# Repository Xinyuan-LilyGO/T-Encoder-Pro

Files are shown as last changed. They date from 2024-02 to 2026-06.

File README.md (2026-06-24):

<!--
 * @Description: None
 * @Author: LILYGO_L
 * @Date: 2023-09-11 16:13:14
 * @LastEditTime: 2026-06-24 11:30:23
 * @License: GPL 3.0
-->
<h1 align = "center">T-Encoder-Pro</h1>

<p align="center" width="100%">
    
</p>

<p> 
  <a href="https://www.arduino.cc/"> Arduino_badge</a>
</p> 

## **English | [中文](./README_CN.md)**

## Version iteration:
| Version | Update date |
| :---: | :---: |
| T-Encoder-Pro_V1.0 | 2024-02-02 |

## PurchaseLink
| Product | SOC |  FLASH  |  PSRAM | Link |
| :---: | :---: |:---: | :---: | :---: |
| T-Encoder-Pro_V1.0 | ESP32S3R8 | 16M |8M (Octal SPI)| [LILYGO Mall](https://www.lilygo.cc/products/t-encoder-plus) <br /> [Banggood Mall](https://m.banggood.in/LILYGO-T-Encoder-Pro-ESP32-S3-Rotary-Encoder-CHSC5816-ESP32-S3FN4R2-Circuit-Board-1_2-inch-AMOLED-Touch-Display-Wireless-Module-p-2018774.html) |

## Directory
- [Describe](#describe)
- [Preview](#preview)
- [Module](#module)
- [QuickStart](#quickstart)
- [PinOverview](#pinoverview)
- [FAQ](#faq)
- [Project](#project)
- [Information](#information)
- [DependentLibraries](#dependentlibraries)

## Describe

 T-Encoder-Pro is a smart control knob equipped with a AMOLED touch screen, based on the ESP32S3R8 chip. The knob rotates, clicks (pushes in), and contains a beeper and vibration motor.

## Preview

### Actual Product Image

<p align="center" width="100%">
    
</p>

---

<p align="center" width="100%">
    
</p>

---

<p align="center" width="100%">
    
</p>

## Module

### 1. MCU

* Chip: ESP32-S3-R8
* PSRAM: 8M (Octal SPI) 
* FLASH: 16M
* For more details, please visit [Espressif ESP32-S3 Datashee](https://www.espressif.com.cn/sites/default/files/documentation/esp32-s3_datasheet_en.pdf)

### 2. Screen and Touch

> **Model: DXQ120MYB2416A**
> * Size: 2.04-inch round screen
> * Screen type: AMOLED
> * Display driver IC: SH8601
> * Touch driver IC: CHSC5816
> * Dependency library: Arduino_GFX
> * Bus communication protocols: QSPI, I2C

> **Model: TFD12MASBCTB4_V0_07**
> * Screen type: AMOLED
> * Display driver IC: CO5300
> * Touch driver IC: CST816
> * Dependency library: Arduino_GFX
> * Bus communication protocols: QSPI, I2C

> [!NOTE]
> TFD12MASBCTB4_V0_07 is the latest version of the screen.

### 3. Rotary Encoder

* Characteristic: Supports left and right rotation

### 4. Buzzer

## QuickStart

### Examples Support

| Example | Support IDE And Version| Description | Picture |
| ---  | ---  | --- | --- |
| [GFX](./examples/GFX) | `[Arduino IDE][esp32_v3.0.7]` |  |  |
| [Lvgl_CIT](./examples/Lvgl_CIT) |`[Arduino IDE][esp32_v3.0.7]` | Product factory original testing |  |
| [CHSC5816](./examples/CHSC5816) | `[Arduino IDE][esp32_v3.0.7]` |  |  |
| [Rotary_Encoder](./examples/Rotary_Encoder) | `[Arduino IDE][esp32_v3.0.7]` |  |  |

| Firmware | Description | Picture |
| ---  | ---  | --- |
| [Lvgl_CIT](./firmware/[T-Encoder-Pro_V1.0][Lvgl_CIT]_firmware_V1.0.0.bin) | factory original testing screenDXQ120MYB2416A |  |
| [Lvgl_CIT](./firmware/(添加开机蜂鸣器)[T-Encoder-Pro_V1.0][Lvgl_CIT][Screen_TFD12MASBCTB4_V0_07]_firmware_202512061209.bin) | factory original testing screen TFD12MASBCTB4_V0_07  |  |

### PlatformIO
1. Install [VisualStudioCode](https://code.visualstudio.com/Download),choose installation based on your system type.

2. Open the "Extension" section of the Visual Studio Code software sidebar (Alternatively, use "<kbd>Ctrl</kbd>+<kbd>Shift</kbd>+<kbd>X</kbd>" to open the extension). Search for the "PlatformIO IDE" extension and download it.

3. During the installation of the extension, you can go to GitHub to download the program. You can download the main branch by clicking on the "<> Code" with green text, or you can download the program versions from the "Releases" section in the sidebar.

4. After the installation of the extension is completed, open the Explorer in the sidebar (Alternatively, use "<kbd>Ctrl</kbd>+<kbd>Shift</kbd>+<kbd>E</kbd>" go open it). Click on "Open Folder", locate the project code you just downloaded (the entire folder), and click "Add." At this point, the project files will be added to your workspace.

5. Open the "platformio.ini" file in the project folder (PlatformIO will automatically open the "platformio.ini" file corresponding to the added folder). Under the "[platformio]" section, uncomment and select the example program you want to burn (it should start with "default_envs = xxx") Then click "<kbd>[√](image/4.png)</kbd>" in the bottom left corner to compile. If the compilation is correct, connect the microcontroller to the computer and click "<kbd>[→](image/5.png)</kbd>" in the bottom left corner to download the program.

### Arduino
1. Install [Arduino](https://www.arduino.cc/en/software), choose installation based on your system type.

2. Open the "example" directory within the project folder, select the example project folder, and open the file ending with ".ino" to open the Arduino IDE project workspace.

3. Open the "Tools" menu at the top right -> Select "Board" -> "Board Manager." Find or search for "esp32" and download the board files from the author named "Espressif Systems." Then, go back to the "Board" menu and select the development board type under "ESP32 Arduino." The selected development board type should match the one specified in the "platformio.ini" file under the [env] section with the header "board = xxx." If there is no corresponding development board, you may need to manually add the development board from the "board" directory within your project folder.

4. Open menu bar "[File](image/6.png)" -> "[Preferences](image/6.png)", find "[Sketchbook location](image/7.png)" here, copy and paste all library files and folders from the "libraries" folder in the project directory into the "libraries" folder in this directory.

5. Select the correct settings in the Tools menu, as shown in the table below.

| Setting | Value |
| :---: | :---: |
| Board | ESP32S3 Dev Module|
| Upload Speed | 921600 |
| USB Mode | Hardware CDC and JTAG |
| USB CDC On Boot | Enabled |
| USB Firmware MSC On Boot | Disabled |
| USB DFU On Boot | Disabled |
| CPU Frequency | 240MHz (WiFi) |
| Flash Mode | QIO 80MHz |
| Flash Size | 16MB (128Mb) |
| Core Debug Level | None |
| Partition Scheme | 16M Flash (3MB APP/9.9MB FATFS) |
| PSRAM | OPI PSRAM |
| Arduino Runs On | Core 1 |
| Events Run On | Core 1 |

6. Select the correct port.

7. Click "<kbd>[√](image/8.png)</kbd>" in the upper right corner to compile. If the compilation is correct, connect the microcontroller to the computer, click "<kbd>[→](image/9.png)</kbd>" in the upper right corner to download.

### Firmware download
1. Open the project file "tools" and locate the ESP32 burning tool. Open it.

2. Select the correct burning chip and burning method, then click "OK." As shown in the picture, follow steps 1->2->3->4->5 to burn the program. If the burning is not successful, press and hold the "BOOT-0" button and then download and burn again.

3. Burn the file in the root directory of the project file "[firmware](./firmware/)" file, there is a description of the firmware file version inside, just choose the appropriate version to download.

<p align="center" width="100%">
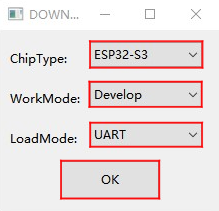
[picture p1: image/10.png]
    
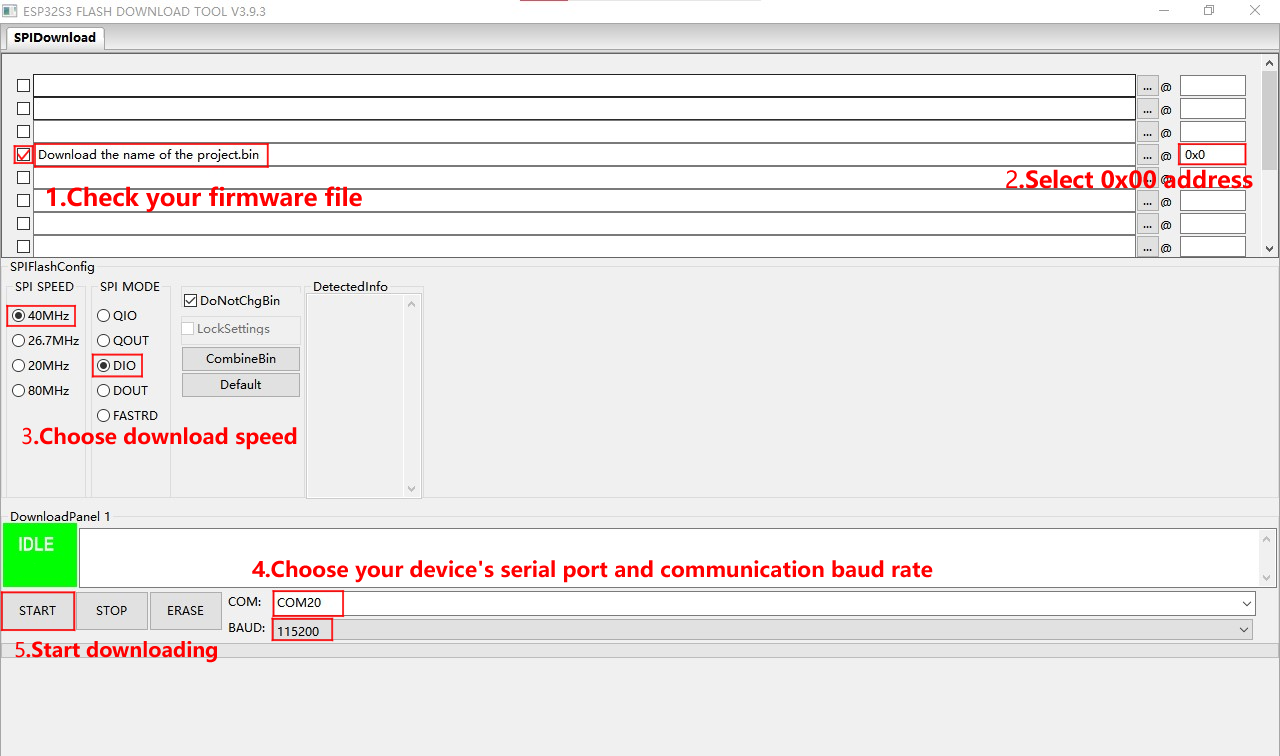
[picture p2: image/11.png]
    
</p>

## PinOverview

| Screen PIN | ESP32S3 PIN |
| :---: | :---:|
| SDIO0 | IO11 |
| SDIO1 | IO13 |
| SDIO2 | IO7 |
| SDIO3 | IO14 |
| SCLK | IO12 |
| RST | IO4 |
| VCI EN |  IO3 |
| CS | IO10 |

| Touch PIN | ESP32S3 PIN |
| :---: | :---:|
| RST | IO8 |
| INT | IO9 |
| SDA | IO5 |
| SCL | IO6 |

| Rotary Encoder PIN | ESP32S3 PIN |
| :---: | :---:|
| KNOB DATA A | IO1 |
| KNOB DATA B | IO2 |
| KNOB KEY | IO0 |

| Buzzer PIN | ESP32S3 PIN |
| :---: | :---:|
| BUZZER DATA | IO17 |

## FAQ

* Q. After reading the above tutorials, I still don't know how to build a programming environment. What should I do?
* A. If you still don't understand how to build an environment after reading the above tutorials, you can refer to the [LilyGo-Document](https://github.com/Xinyuan-LilyGO/LilyGo-Document) document instructions to build it.

<br />

* Q. Why does Arduino IDE prompt me to update library files when I open it? Should I update them or not?
* A. Choose not to update library files. Different versions of library files may not be mutually compatible, so it is not recommended to update library files.

<br />

* Q. Why is there no serial data output on the "Uart" interface on my board? Is it defective and unusable?
* A. The default project configuration uses the USB interface as Uart0 serial output for debugging purposes. The "Uart" interface is connected to Uart0, so it won't output any data without configuration.<br />For PlatformIO users, please open the project file "platformio.ini" and modify the option under "build_flags = xxx" from "-D ARDUINO_USB_CDC_ON_BOOT=true" to "-D ARDUINO_USB_CDC_ON_BOOT=false" to enable external "Uart" interface.<br />For Arduino users, open the "Tools" menu and select "USB CDC On Boot: Disabled" to enable the external "Uart" interface.

<br />

* Q. Why is my board continuously failing to download the program?
* A. Please hold down the "BOOT" button and try downloading the program again.The following is the illustration of the BOOT button.

<p align="center" width="100%">
    BOOT
</p>

<br />

## Project
* [SCH_T-Encoder-Pro_V1.0](project/[SCH][T-Encoder-Pro_V1.0].pdf)
* [SCH_T-Encoder-Pro_V1.0_TFT_FPC](project/[SCH][T-Encoder-Pro_V1.0][TFT_FPC].pdf)

## Information
* [Espressif](https://www.espressif.com/en/support/documents/technical-documents)
* [DXQ120MYB2416A](information/DXQ120MYB2416A.pdf)
* [DS_CHSC5816_V1.1.5](information/DS_CHSC5816_V1.1.5.pdf)
* [CHSC5816-ApplicationDoc_US_V04](information/CHSC5816-ApplicationDoc_US_V04.pdf)

## DependentLibraries
* [Arduino_GFX-1.5.0](https://github.com/moononournation/Arduino_GFX)
* [lvgl-8.3.5](https://github.com/lvgl/lvgl)
* [SensorLib-0.1.4](https://github.com/lewisxhe/SensorsLib)

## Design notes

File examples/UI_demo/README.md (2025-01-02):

This routine runs only in the `PlatformIO` environment

Compilation errors may occur in `Arduino` environments

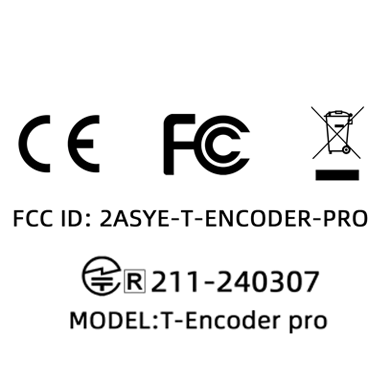
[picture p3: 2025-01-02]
examples/UI_demo/assets/img/electronic_tag.png

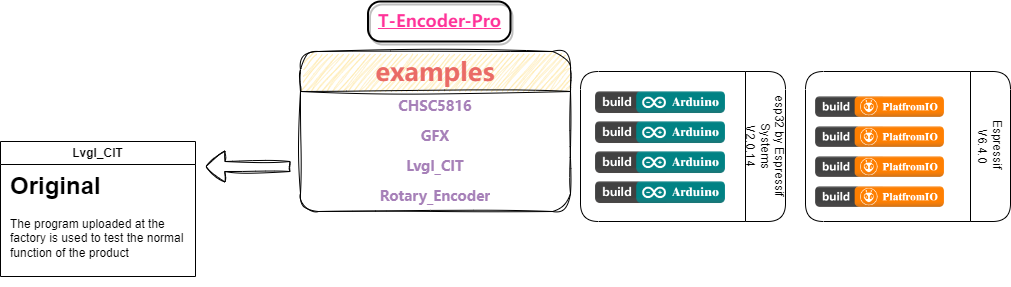
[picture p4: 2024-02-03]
image/T-Encoder-Pro_Example_Support.png

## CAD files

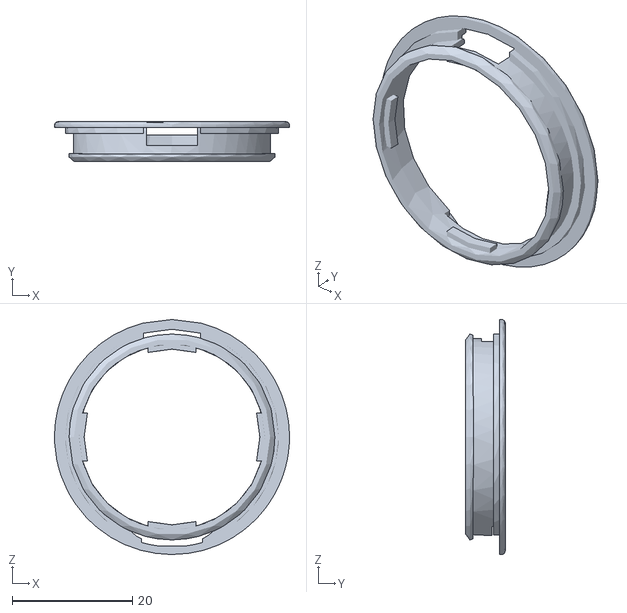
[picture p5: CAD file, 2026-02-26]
structure/H670-STL/0-00_26_4_23_7_30.stl
39.0 x 6.60 x 39.0

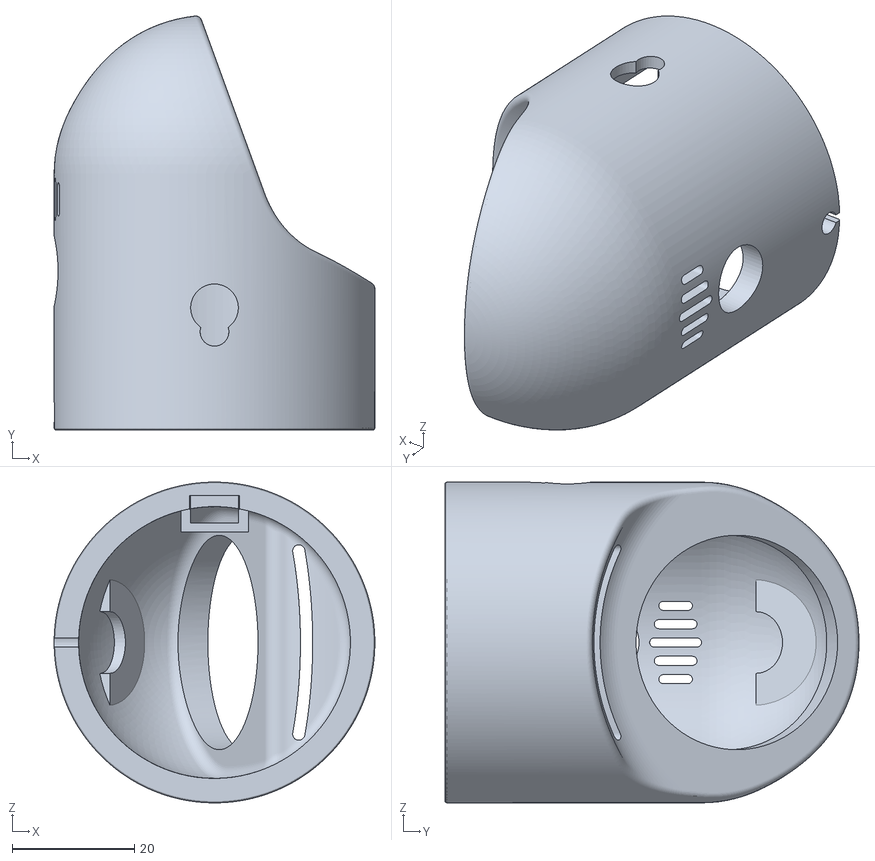
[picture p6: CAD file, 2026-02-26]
structure/zhijia.stl
52.5 x 67.8 x 52.5

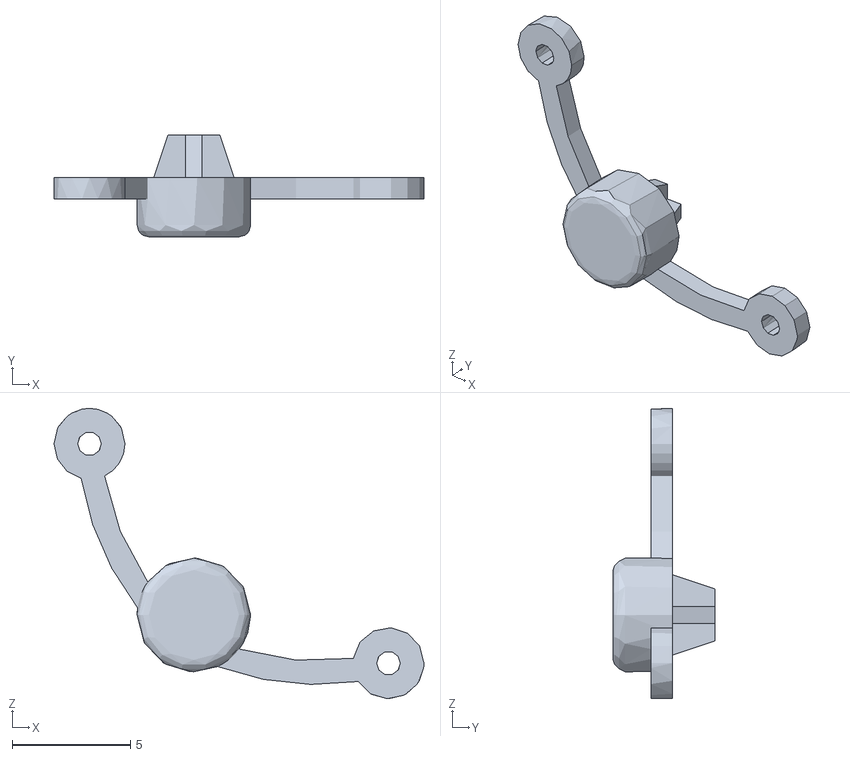
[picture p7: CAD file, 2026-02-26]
structure/H670-STL/0-00_15.stl
15.6 x 4.30 x 12.3

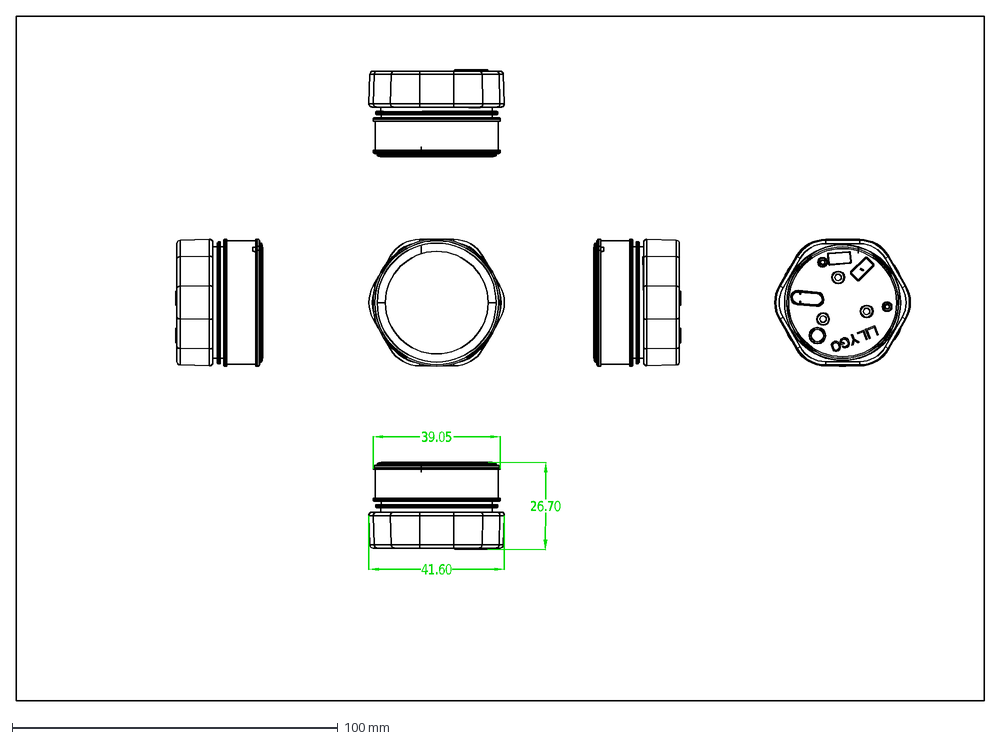
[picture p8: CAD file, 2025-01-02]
structure/Shell.dxf
26.70
41.60
39.05

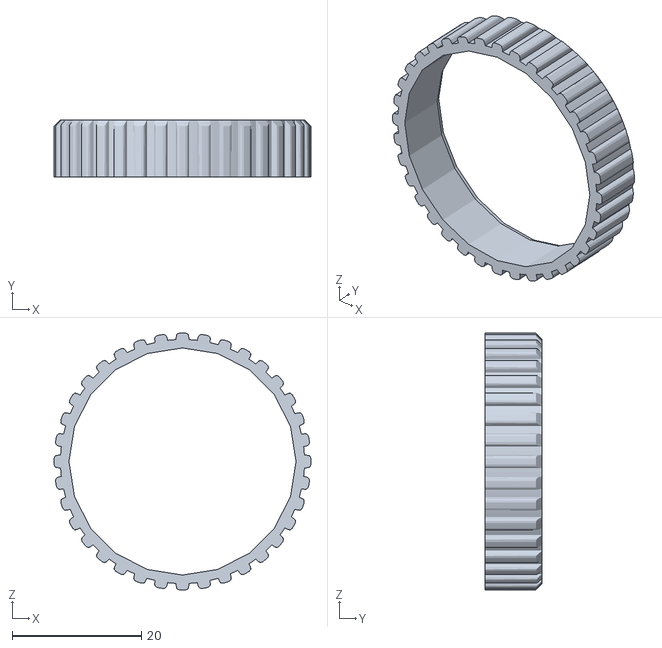
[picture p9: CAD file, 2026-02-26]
structure/H670-STL/0-00_10_5_12.stl
39.8 x 8.90 x 39.8

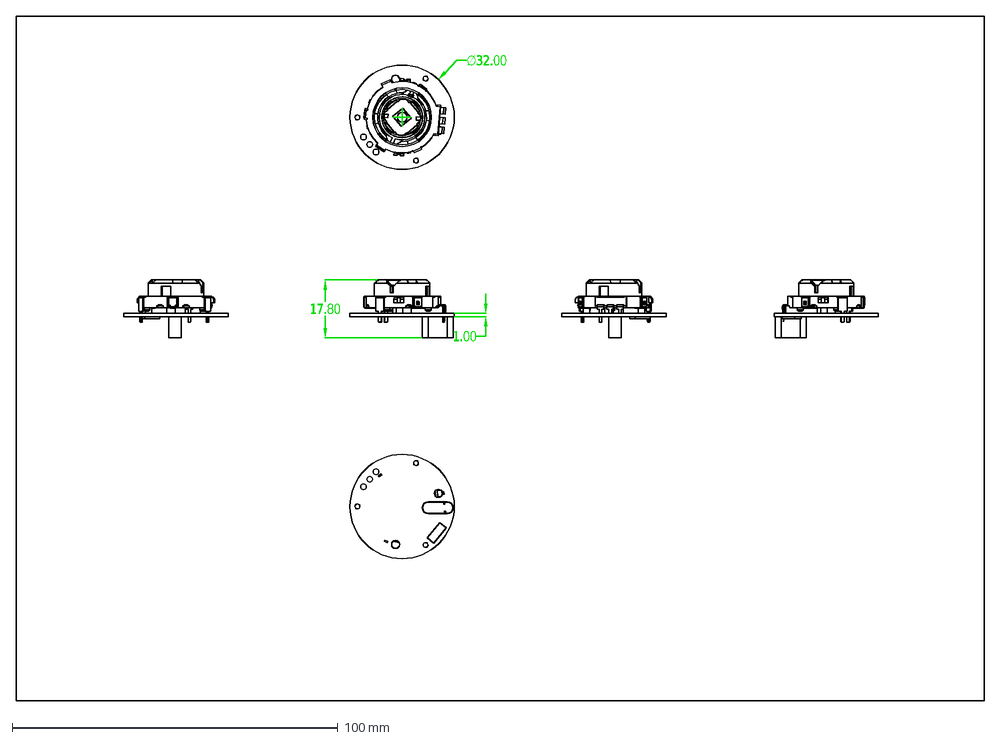
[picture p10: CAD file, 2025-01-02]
structure/PCB.dxf
∅32.00
17.80
1.00

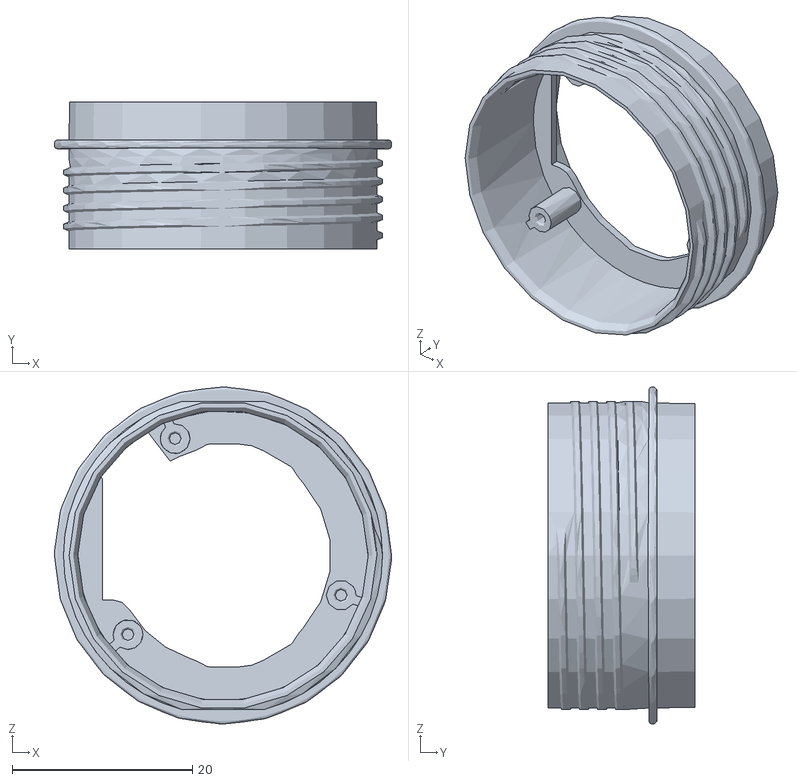
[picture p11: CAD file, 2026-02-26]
structure/H670-STL/0-00_22_30_1.stl
37.4 x 16.3 x 37.4

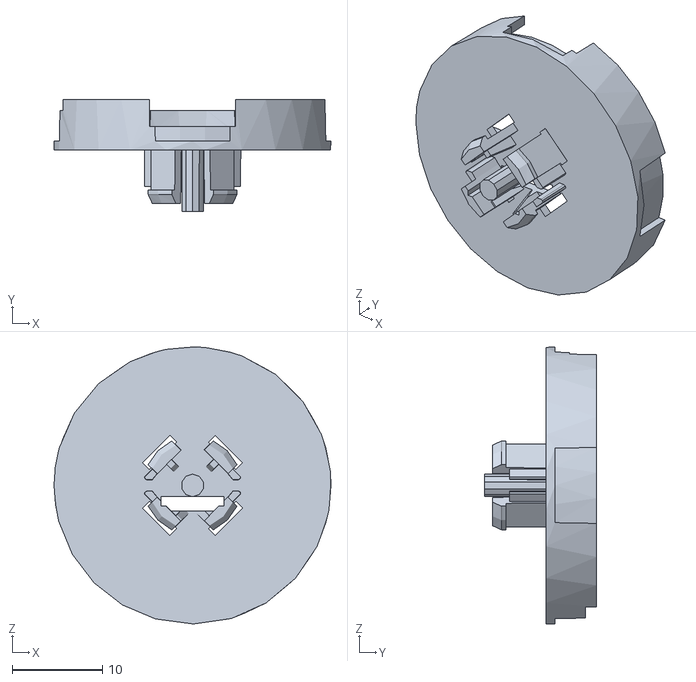
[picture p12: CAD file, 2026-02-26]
structure/H670-STL/0-00_27_3_20_15_33.stl
30.6 x 12.4 x 30.6

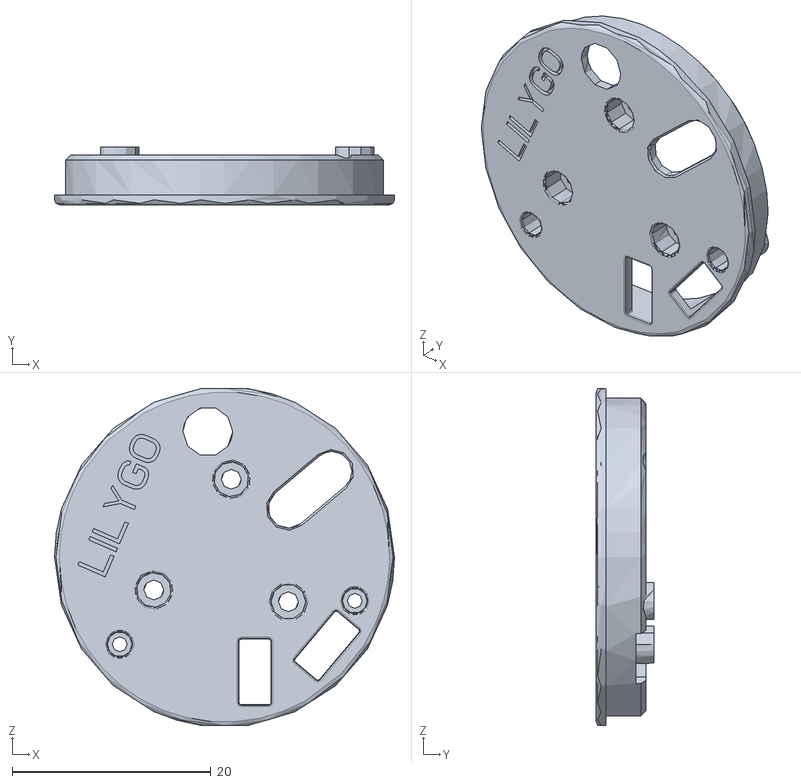
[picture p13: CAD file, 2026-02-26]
structure/H670-STL/0-001_10.stl
34.2 x 5.80 x 33.9

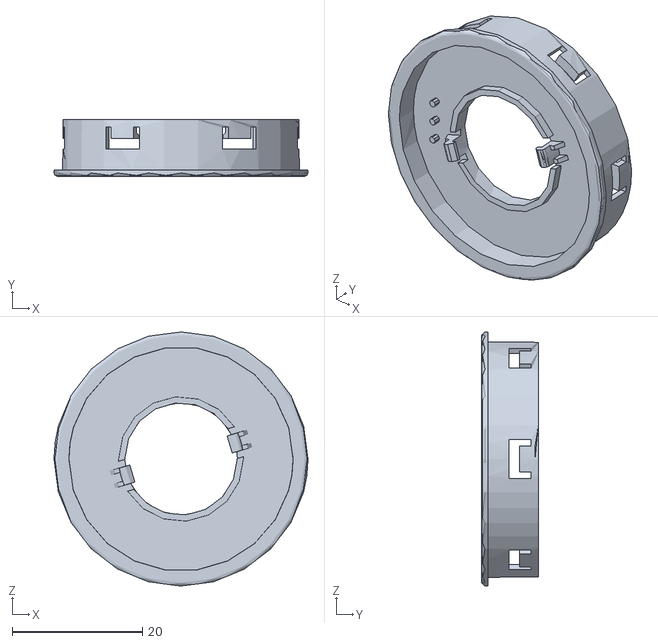
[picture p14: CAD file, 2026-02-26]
structure/H670-STL/0-00_44_4_15_33_10.stl
39.0 x 8.70 x 39.0

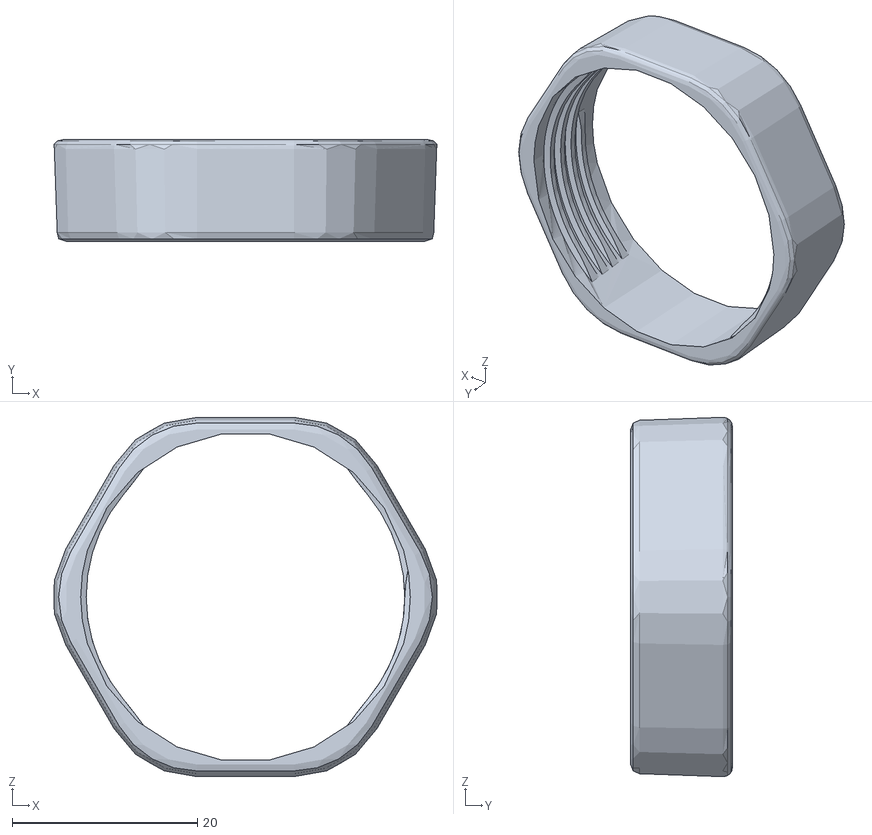
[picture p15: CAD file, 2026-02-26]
structure/H670-STL/0-00_38_1.stl
41.4 x 11.0 x 38.8

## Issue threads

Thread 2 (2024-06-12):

Display physical stability

nikthefix, 2024-06-12:
Received this unit today.
Display looks fantastic!
Love the form factor.
Love the packaging.

On my unit the display glass is able to rotate +/- a degree or so with respect to the main board housing when turning the encoder.
I'm concerned that this can't be good for the FFC connection to the main board.
I imagine it's just tolerances in the sub-assemblies.

Could you upload a step model of the internals?

May I also suggest for future iterations that the encoder silicone ring be increased in diameter to avoid interference with the display glass bezel when operating. 2mm diameter increase would be nice and still look cool and compact.

Many thanks for another terrific product.
Really looking forward to the T-Circle-S3-AMOLED-1.43 and T-Display-AMOLED-1.64

nik

awilley, 2024-07-04:
I agree about the encoder ring. Really needs to be larger. Will still look great.

nikthefix, 2024-07-04:
@awilley
I'm temporarily using the foam insert ring which came in the packaging. It's about the right size for me.
I'm gonna try to construct a contoured brushed aluminium ring - like a mini Nest thermostat.
I think that for this sort of product, an absolute magnetic encoder with no detents would be better. The 'detents' could then be haptics from the mini speaker - nicer for a dial with an undefined application. If the encoder was inductive then the ring hardware could be fabricated from traces on pcb material - no magnets or hall sensors, just a small cheap inductive positional sensor (LX3302A).

awilley, 2024-07-04:
@nikthefix lol, I also kept the foam ring on mine. Shoot me a picture of the ring when you get it built.
I agree about the detents. I was thinking of using a compact haptic motor like 1597-1244-ND (part id) on digikey or similar. Didn't think of just using the speaker, but that's clever and might work well enough depending on the speaker.
That inductive sensor looks really interesting for this.
I think this has to be tried.
Are you planning on putting something together?
I was at one point planning to build a more compact (in height) version of this for some of my small project applications I have.

nikthefix, 2024-07-06:
@awilley Yes I'm preparing an inductive ring design for the 1.43" amoled when it is launched. I only have lilgo drawings at this point but it will be the perfect test bed and saves me having to make a custom board. I already experimented with a linear scale inductive encoder using the Microchip ic. It's a fantastic solution which really works and can be made cheaply to just about any 2D form factor. The esp has to decode the relationship between 2 continuous sinewaves - which it can do with no sweat!

Llgok, 2025-01-02:
Closed due to prolonged inactivity.

Closed 2025-01-02.

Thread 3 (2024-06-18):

Square Line Studio Smart Watch Demo

nikthefix, 2024-06-18:
Here's a demo for the T-Encoder-Pro based on the Square Line Studio Smart Watch Project.
It's refactored for ESP32_Arduino 3.0.1 and requires LVGL 8.3.11 but does not require Arduino_GFX.

Please read the notes at the top of the .ino

[Lilygo_T_Encoder_pro_smart_watch.zip](https://github.com/user-attachments/files/15891249/Lilygo_T_Encoder_pro_smart_watch.zip)

https://github.com/nikthefix/Lilygo_support_T_Encoder_Pro

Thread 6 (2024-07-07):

Errors when compiling examples/GFX/GFX.ino In IDE 2.32

markeby, 2024-07-07:
In file included from c:\Users\markeby\Documents\Arduino\libraries\Arduino_GFX-1.3.7\src/Arduino_GFX_Library.h:4,
from B:\tmp\Encoder\examples\GFX\GFX.ino:16:...\Arduino\libraries\Arduino_GFX-1.3.7\src/Arduino_DataBus.h:167:13: error: 'i80_device_list' has not been declared
167 | LIST_HEAD(i80_device_list, lcd_panel_io_i80_t)

...\Arduino\libraries\Arduino_GFX-1.3.7\src/Arduino_DataBus.h:168:3: error: 'device_list' does not name a type
168 | device_list; // Head of i80 device list

...\Arduino\libraries\Arduino_GFX-1.3.7\src/Arduino_DataBus.h:202:3: error: ISO C++ forbids declaration of 'LIST_ENTRY' with no type [-fpermissive]
202 | LIST_ENTRY(lcd_panel_io_i80_t)

In file included from c:\Users\markeby\Documents\Arduino\libraries\Arduino_GFX-1.3.7\src/Arduino_GFX_Library.h:17:
c:\Users\markeby\Documents\Arduino\libraries\Arduino_GFX-1.3.7\src/databus/Arduino_ESP32RGBPanel.h:43:3: error: 'esp_lcd_rgb_panel_frame_trans_done_cb_t' does not name a type; did you mean 'esp_lcd_panel_io_color_trans_done_cb_t'?
43 | esp_lcd_rgb_panel_frame_trans_done_cb_t on_frame_trans_done; // Callback, invoked after frame trans done

Llgok, 2024-07-10:
@markeby
Currently, the T-Encoder-Pro example code only supports the arduino-esp32-libs_V2.0.14 version. Compiling with the arduino-esp32-libs_V2.0.14 version will not result in any errors.

Closed 2024-07-19.

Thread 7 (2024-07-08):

Issue with compiling T-Encoder Pro Example Sketches

arnie2321, 2024-07-08:
I'm getting lots of errors when compiling the Lvgl_CIT sketch that I pulled from the GitHub examples folder for the T-Encoder Pro.  Mainly seems like issues with library dependencies.   A couple of the other example sketches, Rotary_Encoder and CHSC5816 do compile and run on the T-Encoder.  The GFX example won't compile either.   I'm working in Arduino IDE 2.3.1.  Help from the community or developer would be welcomed.

Lvgl_CIT Compile Errors:

In file included from c:\Users\MyPC\Documents\Arduino\libraries\Arduino_GFX-1.3.7\src/Arduino_GFX_Library.h:4,
                 from C:\Users\MyPC\Documents\Arduino\T-Encoder-Pro-main\examples\Lvgl_CIT\custom.h:13,
                 from C:\Users\MyPC\Documents\Arduino\T-Encoder-Pro-main\examples\Lvgl_CIT\Lvgl_CIT.ino:15:
c:\Users\MyPC\Documents\Arduino\libraries\Arduino_GFX-1.3.7\src/Arduino_DataBus.h:167:13: error: 'i80_device_list' has not been declared
  167 |   LIST_HEAD(i80_device_list, lcd_panel_io_i80_t)
      |             ^~~~~~~~~~~~~~~
c:\Users\MyPC\Documents\Arduino\libraries\Arduino_GFX-1.3.7\src/Arduino_DataBus.h:167:3: error: ISO C++ forbids declaration of 'LIST_HEAD' with no type [-fpermissive]
  167 |   LIST_HEAD(i80_device_list, lcd_panel_io_i80_t)
      |   ^~~~~~~~~
c:\Users\MyPC\Documents\Arduino\libraries\Arduino_GFX-1.3.7\src/Arduino_DataBus.h:167:48: error: expected ';' at end of member declaration
  167 |   LIST_HEAD(i80_device_list, lcd_panel_io_i80_t)
      |                                                ^
      |                                                 ;
c:\Users\MyPC\Documents\Arduino\libraries\Arduino_GFX-1.3.7\src/Arduino_DataBus.h:168:3: error: 'device_list' does not name a type
  168 |   device_list; // Head of i80 device list
      |   ^~~~~~~~~~~
c:\Users\MyPC\Documents\Arduino\libraries\Arduino_GFX-1.3.7\src/Arduino_DataBus.h:202:3: error: ISO C++ forbids declaration of 'LIST_ENTRY' with no type [-fpermissive]
  202 |   LIST_ENTRY(lcd_panel_io_i80_t)
      |   ^~~~~~~~~~
c:\Users\MyPC\Documents\Arduino\libraries\Arduino_GFX-1.3.7\src/Arduino_DataBus.h:202:32: error: expected ';' at end of member declaration
  202 |   LIST_ENTRY(lcd_panel_io_i80_t)
      |                                ^
      |                                 ;
c:\Users\MyPC\Documents\Arduino\libraries\Arduino_GFX-1.3.7\src/Arduino_DataBus.h:203:3: error: 'device_list_entry' does not name a type
  203 |   device_list_entry; // Entry of i80 device list
      |   ^~~~~~~~~~~~~~~~~
In file included from c:\Users\MyPC\Documents\Arduino\libraries\Arduino_GFX-1.3.7\src/Arduino_GFX_Library.h:17:
c:\Users\MyPC\Documents\Arduino\libraries\Arduino_GFX-1.3.7\src/databus/Arduino_ESP32RGBPanel.h:43:3: error: 'esp_lcd_rgb_panel_frame_trans_done_cb_t' does not name a type; did you mean 'esp_lcd_panel_io_color_trans_done_cb_t'?
   43 |   esp_lcd_rgb_panel_frame_trans_done_cb_t on_frame_trans_done; // Callback, invoked after frame trans done
      |   ^~~~~~~~~~~~~~~~~~~~~~~~~~~~~~~~~~~~~~~
      |   esp_lcd_panel_io_color_trans_done_cb_t
C:\Users\MyPC\Documents\Arduino\T-Encoder-Pro-main\examples\Lvgl_CIT\Lvgl_CIT.ino: In function 'void setup()':
C:\Users\MyPC\Documents\Arduino\T-Encoder-Pro-main\examples\Lvgl_CIT\Lvgl_CIT.ino:142:5: error: 'ledcAttachPin' was not declared in this scope; did you mean 'ledcAttach'?
  142 |     ledcAttachPin(BUZZER_DATA, 1);
      |     ^~~~~~~~~~~~~
      |     ledcAttach
C:\Users\MyPC\Documents\Arduino\T-Encoder-Pro-main\examples\Lvgl_CIT\Lvgl_CIT.ino:143:5: error: 'ledcSetup' was not declared in this scope
  143 |     ledcSetup(1, 2000, 8);
      |     ^~~~~~~~~
In file included from c:\Users\MyPC\Documents\Arduino\libraries\Arduino_GFX-1.3.7\src/Arduino_GFX_Library.h:4,
                 from C:\Users\MyPC\Documents\Arduino\T-Encoder-Pro-main\examples\Lvgl_CIT\custom.h:13,
                 from C:\Users\MyPC\Documents\Arduino\T-Encoder-Pro-main\examples\Lvgl_CIT\custom.cpp:14:
c:\Users\MyPC\Documents\Arduino\libraries\Arduino_GFX-1.3.7\src/Arduino_DataBus.h:167:13: error: 'i80_device_list' has not been declared
  167 |   LIST_HEAD(i80_device_list, lcd_panel_io_i80_t)
      |             ^~~~~~~~~~~~~~~
c:\Users\MyPC\Documents\Arduino\libraries\Arduino_GFX-1.3.7\src/Arduino_DataBus.h:167:3: error: ISO C++ forbids declaration of 'LIST_HEAD' with no type [-fpermissive]
  167 |   LIST_HEAD(i80_device_list, lcd_panel_io_i80_t)
      |   ^~~~~~~~~
c:\Users\MyPC\Documents\Arduino\libraries\Arduino_GFX-1.3.7\src/Arduino_DataBus.h:167:48: error: expected ';' at end of member declaration
  167 |   LIST_HEAD(i80_device_list, lcd_panel_io_i80_t)
      |                                                ^
      |                                                 ;
c:\Users\MyPC\Documents\Arduino\libraries\Arduino_GFX-1.3.7\src/Arduino_DataBus.h:168:3: error: 'device_list' does not name a type
  168 |   device_list; // Head of i80 device list
      |   ^~~~~~~~~~~
c:\Users\MyPC\Documents\Arduino\libraries\Arduino_GFX-1.3.7\src/Arduino_DataBus.h:202:3: error: ISO C++ forbids declaration of 'LIST_ENTRY' with no type [-fpermissive]
  202 |   LIST_ENTRY(lcd_panel_io_i80_t)
      |   ^~~~~~~~~~
c:\Users\MyPC\Documents\Arduino\libraries\Arduino_GFX-1.3.7\src/Arduino_DataBus.h:202:32: error: expected ';' at end of member declaration
  202 |   LIST_ENTRY(lcd_panel_io_i80_t)
      |                                ^
      |                                 ;
c:\Users\MyPC\Documents\Arduino\libraries\Arduino_GFX-1.3.7\src/Arduino_DataBus.h:203:3: error: 'device_list_entry' does not name a type
  203 |   device_list_entry; // Entry of i80 device list
      |   ^~~~~~~~~~~~~~~~~
In file included from c:\Users\MyPC\Documents\Arduino\libraries\Arduino_GFX-1.3.7\src/Arduino_GFX_Library.h:17:
c:\Users\MyPC\Documents\Arduino\libraries\Arduino_GFX-1.3.7\src/databus/Arduino_ESP32RGBPanel.h:43:3: error: 'esp_lcd_rgb_panel_frame_trans_done_cb_t' does not name a type; did you mean 'esp_lcd_panel_io_color_trans_done_cb_t'?
   43 |   esp_lcd_rgb_panel_frame_trans_done_cb_t on_frame_trans_done; // Callback, invoked after frame trans done
      |   ^~~~~~~~~~~~~~~~~~~~~~~~~~~~~~~~~~~~~~~
      |   esp_lcd_panel_io_color_trans_done_cb_t
C:\Users\MyPC\Documents\Arduino\T-Encoder-Pro-main\examples\Lvgl_CIT\custom.cpp: In function 'void Window_Rotary_Encoder_WS2812B_Test_Loop()':
C:\Users\MyPC\Documents\Arduino\T-Encoder-Pro-main\examples\Lvgl_CIT\custom.cpp:316:17: error: 'ledcSetup' was not declared in this scope
  316 |                 ledcSetup(1, 1500, 8);
      |                 ^~~~~~~~~
C:\Users\MyPC\Documents\Arduino\T-Encoder-Pro-main\examples\Lvgl_CIT\custom.cpp:372:17: error: 'ledcSetup' was not declared in this scope
  372 |                 ledcSetup(1, 1500, 8);
      |                 ^~~~~~~~~

exit status 1

Compilation error: 'ledcAttachPin' was not declared in this scope; did you mean 'ledcAttach'?

Llgok, 2024-07-10:
@arnie2321
Currently, the T-Encoder-Pro example code only supports the arduino-esp32-libs_V2.0.14 version. Compiling with the arduino-esp32-libs_V2.0.14 version will not result in any errors.

Closed 2024-07-19.

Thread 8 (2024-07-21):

USB Host capabilities ?

jhordies, 2024-07-21:
Hello,
Is it possible to use USB Host via the USB C connector?
The esp spec seems to indicate it is possible but on the product sheet I only read CDC/JTAG.
If it is possible could you provide an example?

PS: I got a t encoder pro hoping to make a project using a USB midi keyboard

Llgok, 2024-07-22:
@jhordies
You can refer to the examples provided by the arduino-esp32 team: [HIDVendor](https://github.com/espressif/arduino-esp32/blob/master/libraries/USB/examples/HIDVendor/HIDVendor.ino) or [USBVendor](https://github.com/espressif/arduino-esp32/blob/master/libraries/USB/examples/USBVendor/USBVendor.ino).

Closed 2024-08-16.

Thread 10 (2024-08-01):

Arduino instructions need updating

eslindsey, 2024-08-01:
### IDE and version or firmware

Arduino IDE 2.3.2

### Operating System

Windows 10

### Description

# Setup

- Uninstalled other boards and libraries.

Performed the steps indicated in the "Arduino" section of the instructions:

- Installed boards esp32 by Espressif Systems 2.0.14 (so this is not related to issue #6 or #7)
- Selected DFRobot Firebeetle 2 ESP32-S3 based on platformio.ini
- Copied library files from the repository to my library directory
- Adjusted the settings in the Tools menu to match those provided, except Board since it contradicts platformio.ini

# Expected Behavior

Example program running on the device.

# Actual Behavior

With Board set according to platformio.ini, compilation succeeds but upload fails:

```
Sketch uses 1883781 bytes (143%) of program storage space. Maximum is 1310720 bytes.
Global variables use 95812 bytes (29%) of dynamic memory, leaving 231868 bytes for local variables. Maximum is 327680 bytes.
Sketch too big; see https://support.arduino.cc/hc/en-us/articles/360013825179 for tips on reducing it.
text section exceeds available space in board
```

With Board set to Adafruit Feather ESP32-S3 No PSRAM, upload is successful.

# Resolution

Instructions should not indicate to choose the board based on platformio.ini. Or, the board in platformio.ini should match the board required for a successful upload (Adafruit Feather ESP32-S3 No PSRAM, per the README).

### Sketch

```cpp
Unmodified code from ./examples/Lvgl_CIT/
```

### Debug Message

```plain
Sketch uses 1898745 bytes (90%) of program storage space. Maximum is 2097152 bytes.
Global variables use 107508 bytes (32%) of dynamic memory, leaving 220172 bytes for local variables. Maximum is 327680 bytes.
esptool.py v4.5.1
Serial port COM10
Connecting...
Chip is ESP32-S3 (revision v0.2)
Features: WiFi, BLE
Crystal is 40MHz
MAC: 64:e8:33:4d:13:00
Uploading stub...
Running stub...
Stub running...
Changing baud rate to 921600
Changed.
Configuring flash size...
Flash will be erased from 0x00000000 to 0x00005fff...
Flash will be erased from 0x00008000 to 0x00008fff...
Flash will be erased from 0x0000e000 to 0x0000ffff...
Flash will be erased from 0x00010000 to 0x001dffff...
Flash will be erased from 0x00410000 to 0x00438fff...
Compressed 22624 bytes to 14245...
Writing at 0x00000000... (100 %)
Wrote 22624 bytes (14245 compressed) at 0x00000000 in 0.4 seconds (effective 425.9 kbit/s)...
Hash of data verified.
Compressed 3072 bytes to 136...
Writing at 0x00008000... (100 %)
Wrote 3072 bytes (136 compressed) at 0x00008000 in 0.1 seconds (effective 411.9 kbit/s)...
Hash of data verified.
Compressed 8192 bytes to 47...
Writing at 0x0000e000... (100 %)
Wrote 8192 bytes (47 compressed) at 0x0000e000 in 0.1 seconds (effective 520.8 kbit/s)...
Hash of data verified.
Compressed 1899104 bytes to 1071477...
Writing at 0x00010000... (1 %)
Writing at 0x0001ba85... (3 %)
Writing at 0x00024fd8... (4 %)
Writing at 0x00030bf8... (6 %)
Writing at 0x000414ce... (7 %)
Writing at 0x00056c66... (9 %)
Writing at 0x00060414... (10 %)
Writing at 0x00066200... (12 %)
Writing at 0x0006c9c6... (13 %)
Writing at 0x00072b2f... (15 %)
Writing at 0x00078879... (16 %)
Writing at 0x0007e1f3... (18 %)
Writing at 0x00083c29... (19 %)
Writing at 0x00089821... (21 %)
Writing at 0x0008f789... (22 %)
Writing at 0x00095130... (24 %)
Writing at 0x0009aa6c... (25 %)
Writing at 0x000a06a7... (27 %)
Writing at 0x000a65b4... (28 %)
Writing at 0x000b363d... (30 %)
Writing at 0x000bda3f... (31 %)
Writing at 0x000c5407... (33 %)
Writing at 0x000cbddc... (34 %)
Writing at 0x000d219e... (36 %)
Writing at 0x000d8877... (37 %)
Writing at 0x000e09c8... (39 %)
Writing at 0x000ee1d5... (40 %)
Writing at 0x000f7314... (42 %)
Writing at 0x00102f19... (43 %)
Writing at 0x00111825... (45 %)
Writing at 0x0011e54d... (46 %)
Writing at 0x00123ff2... (48 %)
Writing at 0x001295b4... (50 %)
Writing at 0x0012e6db... (51 %)
Writing at 0x001335f0... (53 %)
Writing at 0x00138f72... (54 %)
Writing at 0x0013df12... (56 %)
Writing at 0x00143146... (57 %)
Writing at 0x00148270... (59 %)
Writing at 0x0014da04... (60 %)
Writing at 0x0015357a... (62 %)
Writing at 0x00158baa... (63 %)
Writing at 0x0015e29c... (65 %)
Writing at 0x00163897... (66 %)
Writing at 0x001688d4... (68 %)
Writing at 0x0016d69b... (69 %)
Writing at 0x00172636... (71 %)
Writing at 0x001774fd... (72 %)
Writing at 0x0017c708... (74 %)
Writing at 0x00181988... (75 %)
Writing at 0x001868ff... (77 %)
Writing at 0x0018c30a... (78 %)
Writing at 0x001916fa... (80 %)
Writing at 0x0019658b... (81 %)
Writing at 0x0019b669... (83 %)
Writing at 0x001a0751... (84 %)
Writing at 0x001a5a11... (86 %)
Writing at 0x001aafa1... (87 %)
Writing at 0x001b0d59... (89 %)
Writing at 0x001b623c... (90 %)
Writing at 0x001bb846... (92 %)
Writing at 0x001c3ec2... (93 %)
Writing at 0x001cc665... (95 %)
Writing at 0x001d1dfb... (96 %)
Writing at 0x001d76fe... (98 %)
Writing at 0x001dd4c5... (100 %)
Wrote 1899104 bytes (1071477 compressed) at 0x00010000 in 17.2 seconds (effective 883.7 kbit/s)...
Hash of data verified.
Compressed 165536 bytes to 106746...
Writing at 0x00410000... (14 %)
Writing at 0x00418667... (28 %)
Writing at 0x0041dbce... (42 %)
Writing at 0x0042459a... (57 %)
Writing at 0x0042a572... (71 %)
Writing at 0x0042feab... (85 %)
Writing at 0x004352c0... (100 %)
Wrote 165536 bytes (106746 compressed) at 0x00410000 in 1.7 seconds (effective 778.7 kbit/s)...
Hash of data verified.

Leaving...
Hard resetting via RTS pin...
```

### Other steps to Reproduce

_No response_

Llgok, 2024-08-19:
@eslindsey
To use the DFRobot Firebeetle 2 ESP32-S3 development board in the Arduino IDE, you can add the following configurations:
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

Llgok, 2024-09-05:
Closed due to prolonged lack of response

Llgok, 2024-09-05:
Closed due to prolonged lack of response

Closed 2024-09-05.

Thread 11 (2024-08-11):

Misleading schematics and missing buzzer part number

makermoekoe, 2024-08-11:
Nice and neat device - especially the amoled display got me. Therefore I checked the display type, read the datasheet and compared it to the T-Encoder-Pro schematics which contains some inconsistencies.

1. Label of display's TE line (pin 24 of the 24P display connector) is actually not TE but the VCI_EN which is named like this in software correctly (GPIO3). TE is not connected at all ("output a frame head pulse signal") but also doesn't need to.
2. SDIO2 and SDIO3 labels are switched in schematics, but corrected on software side.
3. SDIO0 and SDIO1 labels are switched in schematics, but not corrected in software. Why is it still working?
4. The adaptor PCB with the flex circuit and the display connector seems not to fit the schematics as it additionally contains three resistors next to the four capacitors. Is there a newer schematics version?

So it seems that there are newer schematics available, maybe you can update these in this repository.

And it would be nice if you could add the part number of the tiny buzzer - it sounds and looks very nice. Thanks!

Llgok, 2024-08-21:
@makermoekoe
I'm sorry, I've checked and indeed there are some errors in the hardware schematic. The updated schematic has been fixed. The pin numbers for SDIO0 and SDIO1 are correct. The following image is the data sheet diagram for the buzzer.
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

Closed 2024-08-21.

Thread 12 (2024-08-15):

Upload Failure No serial data received.

jhordies, 2024-08-15:
### IDE and version or firmware

Platform.io

### Operating System

Win10, OSX

### Description

I can connect to the serial port and get some debug traces from ie: Wifi-Test.
But when I try to updload, from Platform.io on both Mac and Windows and even from the Flashing tool, the device restarts, doesn't beep and stays on a black screen.

### Sketch

```cpp
I used the latest version of this repo
```

### Debug Message

```plain
Uploading .pio/build/Rotary_Encoder/firmware.bin
esptool.py v4.5.1
Serial port /dev/cu.usbmodem14201
Connecting...
Chip is ESP32-S3 (revision v0.2)
Features: WiFi, BLE
Crystal is 40MHz
MAC: 64:e8:33:4d:25:68
Uploading stub...
Running stub...
Stub running...
Changing baud rate to 921600

A fatal error occurred: No serial data received.
```

### Other steps to Reproduce

Both Mac and Windows and even from the Flashing tool, the device restarts, doesn't beep and stays on a black screen.
I also tried and installed the VCP drivers on both Mac & Windows https://www.silabs.com/developers/usb-to-uart-bridge-vcp-drivers?tab=downloads without success.
Holding the reset button while plugging it in doesn't help either.

Am I stuck with the demo firmware ?

Llgok, 2024-08-16:
@jhordies
It seems that the computer is not recognizing the USB port of the device. You can try pressing the BOOT button before powering on the device to see if the computer's device manager recognizes a port instead of pressing the reset button. The BOOT button is located inside the middle position of the board's casing and cannot be seen from the outside. You can place the board flat on a table, and pressing the button with a trigger feeling on the screen indicates that you have pressed the BOOT button.
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

jhordies, 2024-08-16:
Thank you!
It worked from the first try, keep the device squeezed while connecting the USB port, and the upload worked flawlessly.I kept it pressed (might not be needed) during the all process.
I think this deserves to be in the readme as I spent quite some time in this issue without guessing the right button to press. It could be useful to other noobs

Closed 2024-08-16.

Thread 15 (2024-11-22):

platformio.ini missing

Printasaurus, 2024-11-22:
The description says something about the platformio.ini.
But I am not able to find the file in the project (for the newest branch).

Best regards

Llgok, 2024-12-06:
The latest branch is based on arduino-esp32-libs_V3.0.7, which does not support PlatformIO programming, so there is no `platformio.ini` file. For versions 3.0 and above, please use the Arduino IDE for compilation. If you wish to use PlatformIO for programming, please visit the [arduino-esp32-libs_V2.0.4](https://github.com/Xinyuan-LilyGO/T-Encoder-Pro/tree/arduino-esp32-libs_V2.0.14)

Llgok, 2025-01-02:
Closed due to prolonged inactivity.

Closed 2025-01-02.

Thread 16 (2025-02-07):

p: /Users/jimmurray/Library/Arduino15/packages/esp32/hardware/esp32/3.1.1/tools/partitions/{build.partitions}.csv: No such file or directory

AC-5ME, 2025-02-07:
I think I've followed the directions but I can't compile, any ideas?  Thanks!

Llgok, 2025-02-14:
@AC-5ME
Hello, which [example](https://github.com/Xinyuan-LilyGO/T-Encoder-Pro/tree/arduino-esp32-libs_V3.0.7/examples) program are you using for compilation?

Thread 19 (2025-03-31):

Need example to program with i2c.

eltonask, 2025-03-31:
### What features or library support or other would you like to add?

_No response_

### Additional context.

_No response_

Llgok, 2025-04-02:
@eltonask The [CHSC5816.ino](https://github.com/Xinyuan-LilyGO/T-Encoder-Pro/tree/arduino-esp32-libs_V3.0.7/examples/CHSC5816) example uses i2c communication, believe this example will be helpful to you.

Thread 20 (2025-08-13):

pin_config.h missing

rumoldus, 2025-08-13:
### Operating System

Windows 11 64 bit Intel

### IDE

Arduino 2.3.6

### Software Package Version

ESP32S3 DEV Module from Espressif ESP boards 3.3.0 by Espressif

### Description

Trying to run the most simple example of rotary_encoder and it fails on the 2nd line. "include "pin_config.h". This file does not exist in the whole T_encoder pro folder structure. There is also no instruction in the INO file to create this file or where to find it. Very disappointing that the most simple example cannot be run.

### Sketch

```cpp
#include <Arduino.h>
#include "pin_config.h"
```

### Debug Message

```plain
...\T-Encoder-Pro-arduino-esp32-libs_V3.0.7\examples\Rotary_Encoder\Rotary_Encoder.ino:9:10: fatal error: pin_config.h: No such file or directory
    9 | #include "pin_config.h"
      |          ^~~~~~~~~~~~~~
compilation terminated.
exit status 1

Compilation error: pin_config.h: No such file or directory
```

### Other steps to Reproduce

_No response_

Llgok, 2025-08-14:
@rumoldus
The pin_config.h file is located in the [./libraries/Mylibrary/pin_config.h directory](https://github.com/Xinyuan-LilyGO/T-Encoder-Pro/blob/arduino-esp32-libs_V3.0.7/libraries/Mylibrary/pin_config.h). You need to manually move it to the Arduino library directory.

For the moving operation, please refer to [QuickStart](https://github.com/Xinyuan-LilyGO/T-Encoder-Pro?tab=readme-ov-file#arduino).

rumoldus, 2025-08-14:
Many thanks for the very quick reaction.

Closed 2025-08-15.

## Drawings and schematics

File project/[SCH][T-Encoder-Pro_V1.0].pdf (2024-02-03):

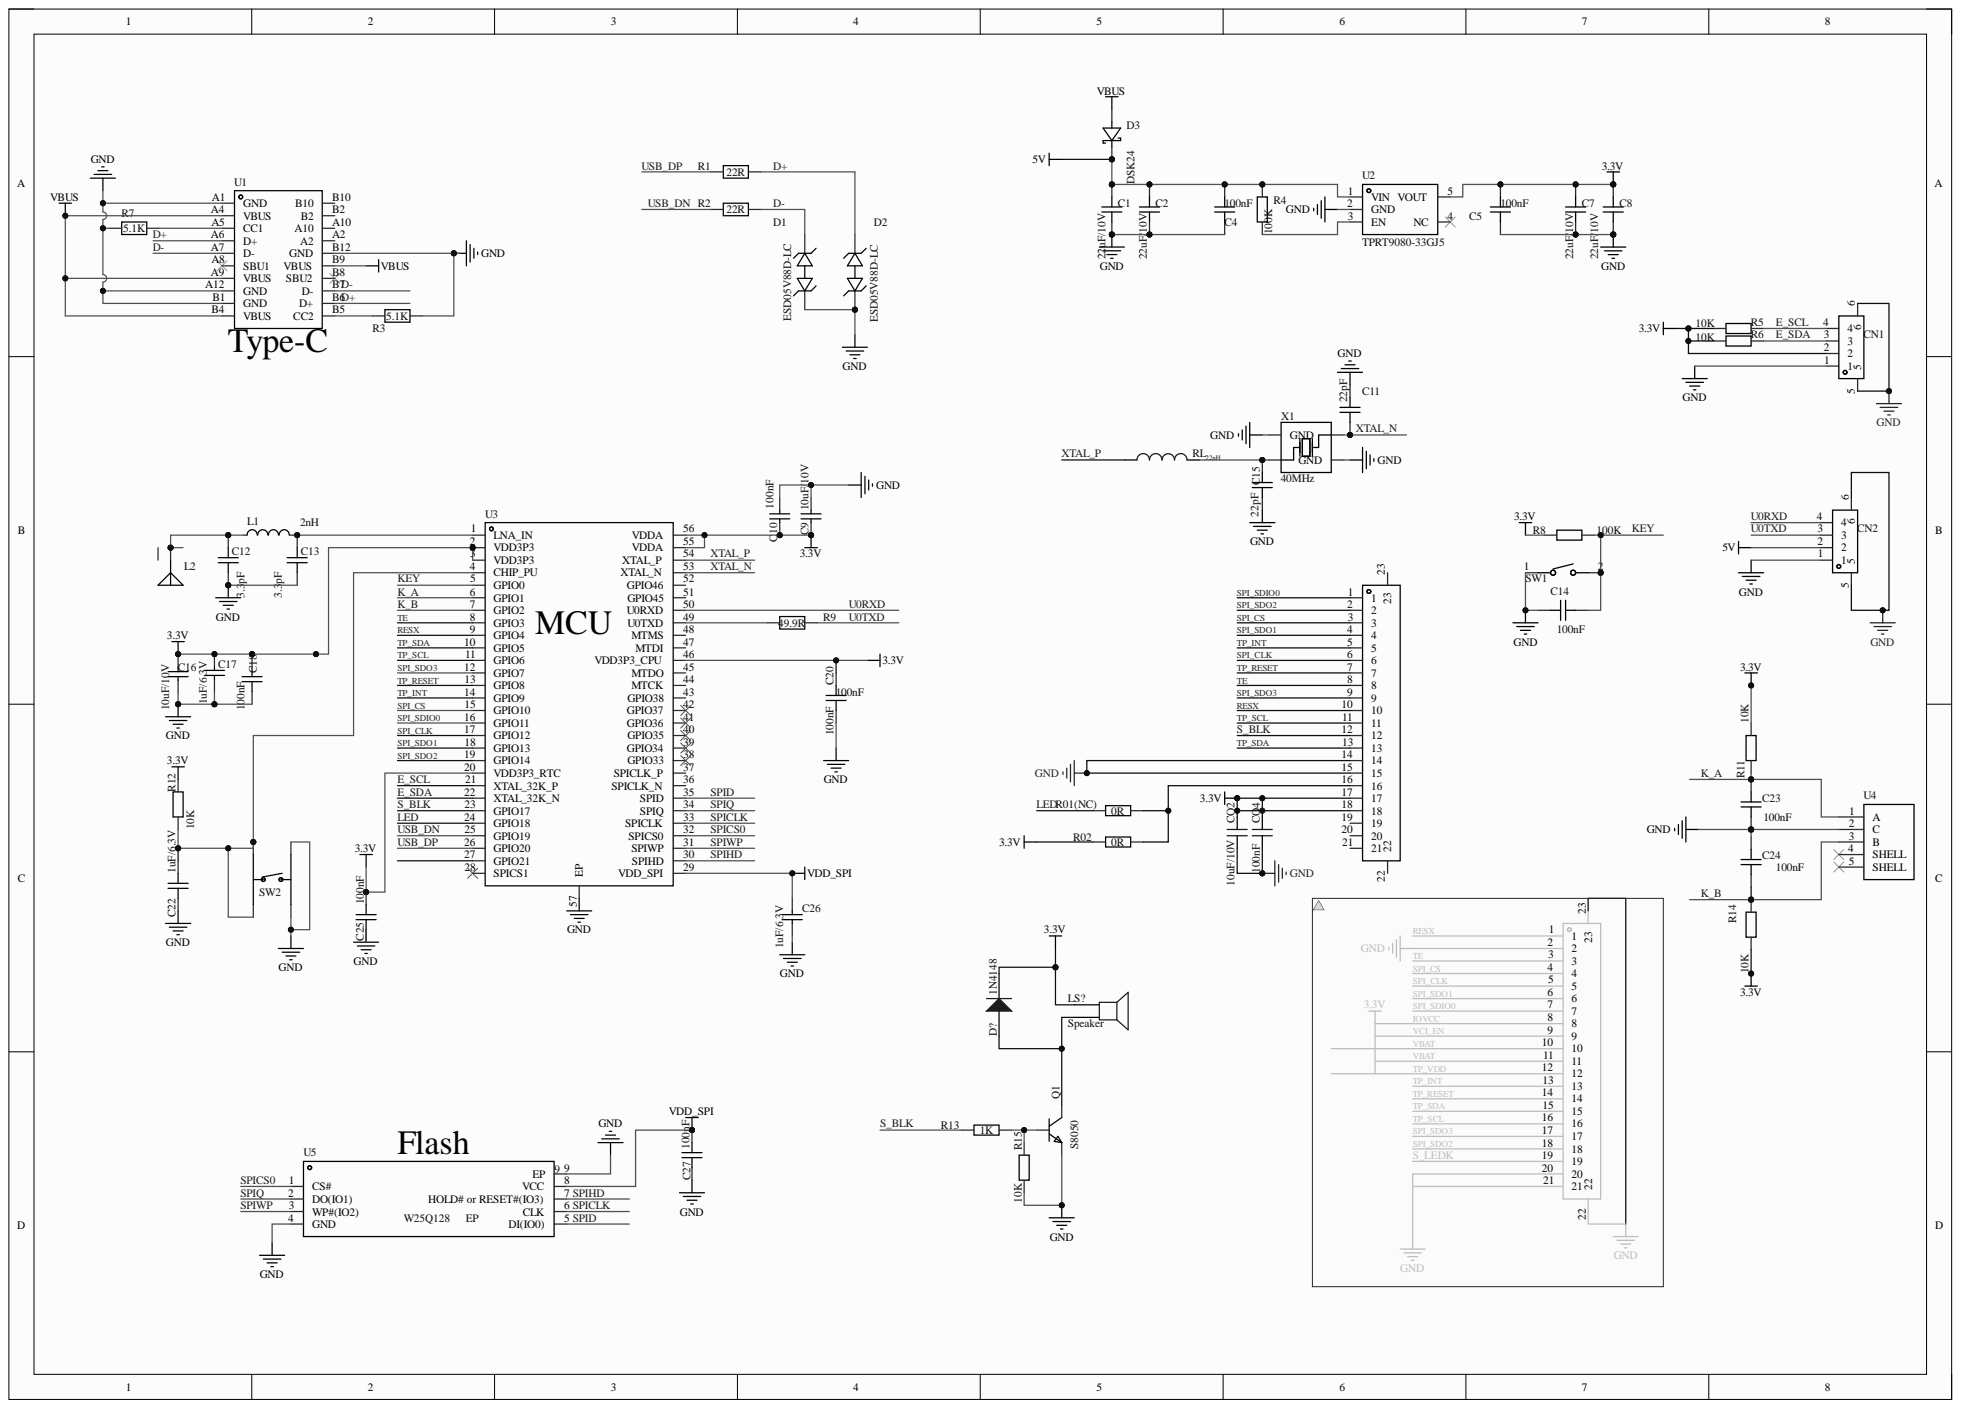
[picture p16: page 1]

A12 | | B
B | 1 | B 6 D +

17 17
18 18

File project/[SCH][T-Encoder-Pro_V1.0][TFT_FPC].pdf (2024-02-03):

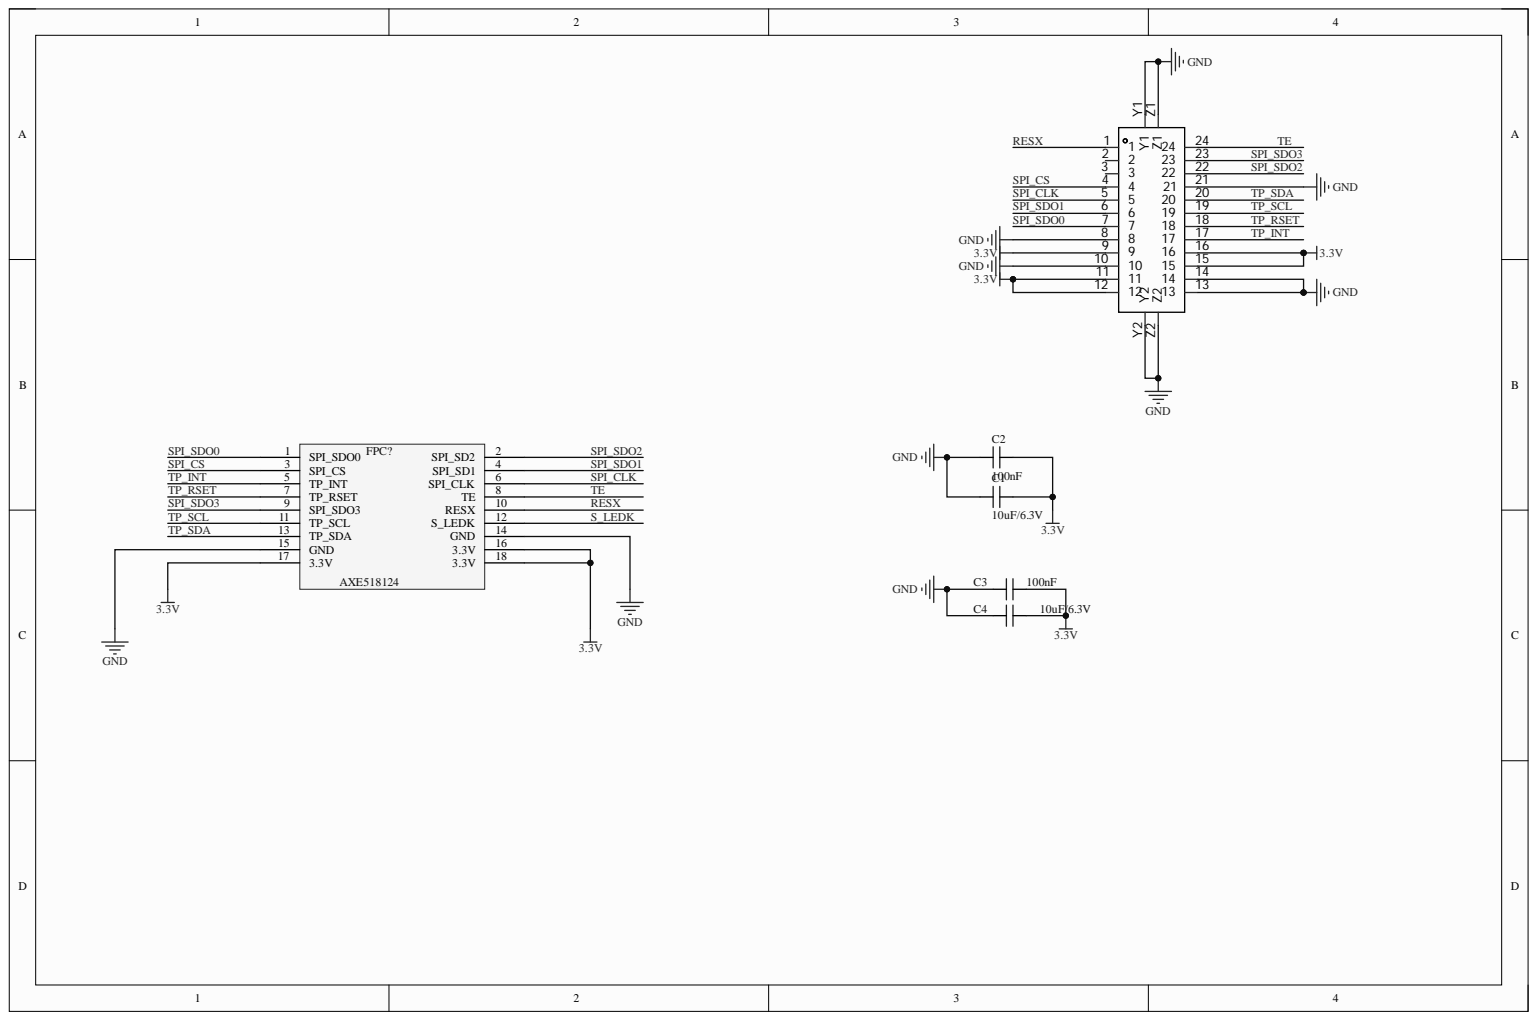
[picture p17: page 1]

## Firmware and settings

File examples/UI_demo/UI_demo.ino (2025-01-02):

#include "ui.h"
#include "screen/screen.h"
#include "port/lv_port_disp.h"
#include "port/lv_port_indev.h"
#include "pin_config.h"
#include <WiFi.h>
#include <FastLED.h>
#include "EEPROM.h"
#include <ESP32Servo.h>
/*********************************************************************************
 *                              EXTERN
 *********************************************************************************/
extern Arduino_GFX *gfx;

extern uint16_t brightness_level;
extern bool touch_line_state;
extern uint16_t input_mode;
extern bool menu_label_align_to_tgt;
/*********************************************************************************
 *                              TYPEDEFS
 *********************************************************************************/
// wifi
const char* ssid = "xinyuandianzi";
const char* password = "AA15994823428";
const char *ntpServer1 = "pool.ntp.org";
const char* ntpServer2 = "time.nist.gov";
bool is_connect_wifi = false;
static struct tm timeinfo;
static uint32_t last_tick;
// ws2812
static CRGB ws2812_leds[WS2812B_LED_NUM];
// eeprom
uint8_t eeprom_buf[EEPROM_SIZE_MAX] = {0};
// servo motor
Servo myservo;

static bool ui_init = false;
/*********************************************************************************
 *                              FUNCTION
 *********************************************************************************/
void eeprom_write(int addr, uint8_t val)
{
    eeprom_buf[EEPROM_UPDATA_FLAG_ADDR] = EEPROM_UPDATA_FLAG_NUM;
    eeprom_buf[addr] = val;

    for(int i = 0; i < EEPROM_SIZE_MAX; i++){
        EEPROM.write(i, eeprom_buf[i]);
    }
    EEPROM.commit();
    for (int i = 0; i < EEPROM_SIZE_MAX; i++) {
        Serial.print(byte(EEPROM.read(i))); Serial.print(" ");
    }
    Serial.println("");
}

static void msg_subsribe_event(void * s, lv_msg_t * msg)
{
    LV_UNUSED(s);

    switch (msg->id)
    {
        case MSG_DISP_BRIGHTNESS:{
            static uint8_t prev_val = 0;
            uint16_t *v = (uint16_t *)lv_msg_get_payload(msg);
            if(prev_val != *v){
                prev_val = *v;
                uint8_t tmp = lv_map(*v, 1, 10, 50, 255);
                gfx->Display_Brightness(tmp);
                eeprom_write(EEPROM_DISPLAY_LIGHT_ADDR, prev_val);
            }
            break;
        }
        case MSG_TOUCH_LINE:{
            bool *v = (bool *)lv_msg_get_payload(msg);
            in_indev_touchpad_line_en(*v);
            eeprom_write(EEPROM_TOUCH_LINE_ADDR, byte(*v));
            break;
        }
        case MSG_INDEV_MODE:{
            uint16_t *v = (uint16_t *)lv_msg_get_payload(msg);
            eeprom_write(EEPROM_INDEV_MODE_ADDR, byte(*v));
            break;
        }
        case MSG_MENU_LABEL_ALIGN:{
            bool *v = (bool *)lv_msg_get_payload(msg);
            eeprom_write(EEPROM_MENU_LABEL_ADDR, byte(*v));
            break;
        }
        case MSG_WS2812_LIGHT:{
            int32_t *v = (int32_t *)lv_msg_get_payload(msg);
            printf("ws2812 light = %d\n", *v);
            FastLED.setBrightness(*v);
            FastLED.show();
            break;
        }
        case MSG_WS2812_COLOR:{
            uint8_t *v = (uint8_t *)lv_msg_get_payload(msg);
            CRGB c;
            c.red = v[0];
            c.green = v[1];
            c.blue = v[2];
            printf("r=0x%x, g=0x%x, b=0x%x\n",c.red, c.green, c.blue);
            for(int i = 0; i < WS2812B_LED_NUM; i++){
                uint32_t t = c.red << 16 | c.green << 8 | c.blue;
                ws2812_leds[i] = c;
            }
            // FastLED.show();
            break;
        }
        case MSG_METER_SPEED:{
            int32_t *v = (int32_t *)lv_msg_get_payload(msg);
            printf("ws2812 light = %d\n", *v);
            FastLED.setBrightness(*v);
            FastLED.show();
            break;
        }
        case MSG_METER_TEMPERTRUE:{
            int32_t *v = (int32_t *)lv_msg_get_payload(msg);
            printf("speed_value=%d\n", *v);
            break;
        }
        default:
            break;
    }
}

static void msg_send_event(lv_timer_t *t)
{
    if(screen1_no_exit == true && is_connect_wifi == true){
        if (!getLocalTime(&timeinfo)){
            Serial.println("Failed to obtain time");
            return;
        }
        Serial.println(&timeinfo, "%F %T %A"); // 格式化输出
        timeinfo.tm_hour = timeinfo.tm_hour % 12;
        lv_msg_send(MSG_CLOCK_HOUR, &timeinfo.tm_hour);
        lv_msg_send(MSG_CLOCK_MINUTE, &timeinfo.tm_min);
        lv_msg_send(MSG_CLOCK_SECOND, &timeinfo.tm_sec);
    }
    // eeprom_write(-1, 0);

    static int cnt = 0;
    cnt++;
    if((cnt > 4) && (ui_init == false)) {
        ui_init = true;
        ui_entry();
    }
}

void wifi_init(void)
{
    WiFi.begin(ssid, password);
    wl_status_t wifi_state = WiFi.status();
    last_tick = millis();
    while (wifi_state != WL_CONNECTED){
        delay(500);
        Serial.print(".");
        wifi_state = WiFi.status();
        if(wifi_state == WL_CONNECTED){
            is_connect_wifi = true;
            Serial.println("WiFi connected!");
            configTime(8 * 3600, 0, ntpServer1, ntpServer2);
            break;
        }
        if (millis() - last_tick > 5000) {
            Serial.println("WiFi connected falied!");
            last_tick = millis();
            break;
        }
    }
}

void eeproom_init(void)
{
    if (!EEPROM.begin(EEPROM_SIZE_MAX)) {
        Serial.println("failed to initialise EEPROM"); delay(1000000);
    }
    Serial.println(" bytes read from Flash . Values are:");

    for (int i = 0; i < EEPROM_SIZE_MAX; i++) {
        eeprom_buf[i] = EEPROM.read(i);
        Serial.print(byte(EEPROM.read(i))); Serial.print(" ");
    }

    uint8_t frist_read = eeprom_buf[EEPROM_UPDATA_FLAG_ADDR];
    Serial.printf(" read = %d\n", frist_read);
    if(frist_read == EEPROM_UPDATA_FLAG_NUM){
        brightness_level = eeprom_buf[EEPROM_DISPLAY_LIGHT_ADDR];
        touch_line_state = eeprom_buf[EEPROM_TOUCH_LINE_ADDR];
        input_mode = eeprom_buf[EEPROM_INDEV_MODE_ADDR];
        menu_label_align_to_tgt = eeprom_buf[EEPROM_MENU_LABEL_ADDR];

        in_indev_touchpad_line_en(touch_line_state);
        uint8_t tmp = lv_map(brightness_level, 1, 10, 50, 255);
        gfx->Display_Brightness(tmp);
    }else{
        lv_memset_00(eeprom_buf, EEPROM_SIZE_MAX);
        eeprom_buf[EEPROM_UPDATA_FLAG_ADDR]= EEPROM_UPDATA_FLAG_NUM;
        eeprom_buf[EEPROM_DISPLAY_LIGHT_ADDR]= 10;
        eeprom_buf[EEPROM_TOUCH_LINE_ADDR]= 0;
        eeprom_buf[EEPROM_INDEV_MODE_ADDR]= 0;
        eeprom_buf[EEPROM_MENU_LABEL_ADDR]= 0;
        for(int i = EEPROM_UPDATA_FLAG_ADDR; i < EEPROM_SIZE_MAX; i++){
            EEPROM.write(i, eeprom_buf[i]);
        }
        EEPROM.commit();
    }
}

int calculatePWM(int pos)
{   
    for (pos = 0; pos <= 180; pos += 1) { // goes from 0 degrees to 180 degrees
    // in steps of 1 degree
        myservo.write(pos);              // tell servo to go to position in variable 'pos'
        delay(15);                       // waits 15 ms for the servo to reach the position
    }
    for (pos = 180; pos >= 0; pos -= 1) { // goes from 180 degrees to 0 degrees
        myservo.write(pos);              // tell servo to go to position in variable 'pos'
        delay(15);                       // waits 15 ms for the servo to reach the position
    }
    return 0;
}


TaskHandle_t servo_handle;
int touch_state;
int pos;
void servo_task(void *param)
{
    while (1)
    {
        if(touch_state == LOW){
            for (pos = 0; pos <= 180; pos += 1) { // goes from 0 degrees to 180 degrees
            // in steps of 1 degree
                myservo.write(pos);              // tell servo to go to position in variable 'pos'
                delay(15);                       // waits 15 ms for the servo to reach the position
                if(pos == 180) {
                    vTaskSuspend(servo_handle);
                    Serial.println("servo suspend");
                }
            }
        }else{
            for (pos = 180; pos >= 0; pos -= 1) { // goes from 180 degrees to 0 degrees
                myservo.write(pos);    // tell servo to go to position in variable 'pos'
                delay(15);             // waits 15ms for the servo to reach the position
                if(pos == 0) {
                    vTaskSuspend(servo_handle);
                    Serial.println("servo suspend");
                }
            }
        }
    }
}

void touch_btn_irq_event(void)
{
    touch_state = digitalRead(TOUCH_KEY_PRESS_PIN);
    vTaskResume(servo_handle);
    Serial.printf("Touch curr %s\n", touch_state == LOW ? "LOW" : "HIGH");
}

void setup()
{
    Serial.begin(115200);

    delay(3000);

    pinMode(TOUCH_KEY_PRESS_PIN, INPUT); // Touch Btn
    ESP32PWM::allocateTimer(0);
	ESP32PWM::allocateTimer(1);
	ESP32PWM::allocateTimer(2);
	ESP32PWM::allocateTimer(3);
	myservo.setPeriodHertz(50);    // standard 50 hz servo
	myservo.attach(SERVO_MOTORS, 1000, 2000);
    attachInterrupt(TOUCH_KEY_PRESS_PIN, touch_btn_irq_event, CHANGE);

    wifi_init();

    lv_init();

    lv_port_disp_init();

    lv_port_indev_init();
    
    // ui_entry();

    eeproom_init();

    lv_timer_create(msg_send_event, 1000, NULL);
    
    // ws2812
    FastLED.addLeds<WS2812B, WS2812B_DATA, GRB>(ws2812_leds, WS2812B_LED_NUM); // GRB ordering is typical
    for(int i = 0; i < WS2812B_LED_NUM; i++){
        ws2812_leds[i] = 0x8617fd;
    }
    FastLED.setBrightness(0);
    FastLED.show();
    
    // lvgl msg
    lv_msg_subsribe(MSG_DISP_BRIGHTNESS, msg_subsribe_event, NULL);
    lv_msg_subsribe(MSG_TOUCH_LINE, msg_subsribe_event, NULL);
    lv_msg_subsribe(MSG_INDEV_MODE, msg_subsribe_event, NULL);
    lv_msg_subsribe(MSG_MENU_LABEL_ALIGN, msg_subsribe_event, NULL);
    lv_msg_subsribe(MSG_WS2812_LIGHT, msg_subsribe_event, NULL);
    lv_msg_subsribe(MSG_WS2812_COLOR, msg_subsribe_event, NULL);
    lv_msg_subsribe(MSG_METER_SPEED, msg_subsribe_event, NULL);
    lv_msg_subsribe(MSG_METER_TEMPERTRUE, msg_subsribe_event, NULL);

    xTaskCreate(servo_task, "servo_task", 1024 * 3, NULL, 2, &servo_handle);


    lv_obj_t *img = lv_img_create(lv_scr_act());
    lv_img_set_src(img, &electronic_tag);
    lv_obj_center(img);
}

int16_t angle = 0;
int16_t ws2812_cnt=0;
void ws2812_eff1(void)
{
    if(FastLED.getBrightness() == 0) {
        return;
    }

    ws2812_cnt++;
    if(ws2812_cnt > 5){
        ws2812_cnt = 0;
        angle += 1;
        for(int i = 0; i < WS2812B_LED_NUM; i++){
            int16_t a = lv_trigo_sin(angle + i*5);
            CRGB c;
            c.red = lv_map(a, -32767, 32767, 0, 255);
            // c.green = lv_map(a, -32767, 32767, 0, 255);
            // c.blue = lv_map(a, -32767, 32767, 0, 255);
            ws2812_leds[i] = c;
        }
        FastLED.show();
    }
}

void loop()
{
    lv_timer_handler(); /* let the GUI do its work */
    delay(1);

    ws2812_eff1();
}

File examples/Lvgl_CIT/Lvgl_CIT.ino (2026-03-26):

/*
 * @Description: This is a user testing program CIT written for T-Encoder-Pro.
 * @Author: LILYGO_L
 * @Date: 2025-09-16 13:31:12
 * @LastEditTime: 2026-03-26 14:38:58
 * @License: GPL 3.0
 */
#include "custom.h"
#include "lvgl.h"
#include "gui_guider.h"
#include "events_init.h"
#include "TouchDrvCHSC5816.hpp"
#include "material_16bit.h"
#include "Arduino_DriveBus_Library.h"

static size_t Window_CycleTime1 = 0;

static lv_disp_draw_buf_t draw_buf;
static lv_disp_drv_t disp_drv;

// DXQ120MYB2416A
Arduino_DataBus *bus = new Arduino_ESP32QSPI(
    SCREEN_CS /* CS */, SCREEN_SCLK /* SCK */, SCREEN_SDIO0 /* SDIO0 */,
    SCREEN_SDIO1 /* SDIO1 */, SCREEN_SDIO2 /* SDIO2 */, SCREEN_SDIO3 /* SDIO3 */);

#if defined DXQ120MYB2416A
TouchDrvCHSC5816 touch;
TouchDrvInterface *pTouch;

Arduino_GFX *gfx = new Arduino_SH8601(bus, SCREEN_RST /* RST */, 0 /* rotation */,
                                      false /* IPS */, SCREEN_WIDTH, SCREEN_HEIGHT);
#elif defined TFD12MASBCTB4_V0_07

std::shared_ptr<Arduino_IIC_DriveBus> IIC_Bus =
    std::make_shared<Arduino_HWIIC>(IIC_SDA, IIC_SCL, &Wire);

void Arduino_IIC_Touch_Interrupt(void);

std::unique_ptr<Arduino_IIC> CST816D(new Arduino_CST816x(IIC_Bus, CST816D_DEVICE_ADDRESS,
                                                         TOUCH_RST, TOUCH_INT, Arduino_IIC_Touch_Interrupt));

void Arduino_IIC_Touch_Interrupt(void)
{
    CST816D->IIC_Interrupt_Flag = true;
}

Arduino_GFX *gfx = new Arduino_CO5300(bus, SCREEN_RST /* RST */,
                                      0 /* rotation */, false /* IPS */, SCREEN_WIDTH, SCREEN_HEIGHT,
                                      0 /* col offset 1 */, 0 /* row offset 1 */, 0 /* col_offset2 */, 0 /* row_offset2 */);
#else
#error "Unknown macro definition. Please select the correct macro definition."
#endif

lv_ui guider_ui;
Lvgl_CIT_UI CIT_UI;

void Touch_Initialization(void)
{
#if defined DXQ120MYB2416A
    TouchDrvCHSC5816 *pd1 = static_cast<TouchDrvCHSC5816 *>(pTouch);

    touch.setPins(TOUCH_RST, TOUCH_INT);
    if (!touch.begin(Wire, CHSC5816_SLAVE_ADDRESS, IIC_SDA, IIC_SCL))
    {
        Serial.println("Failed to find CHSC5816 - check your wiring!");
        // while (1)
        // {
        //     delay(1000);
        // }
    }
    else
    {
        Serial.println("Init CHSC5816 Touch device success!");
    }
#elif defined TFD12MASBCTB4_V0_07
    if (CST816D->begin() == false)
    {
        Serial.println("CST816D initialization fail");
    }
    else
    {
        Serial.println("CST816D initialization successfully");

        // 中断模式为检测到触摸时，发出低脉冲
        CST816D->IIC_Write_Device_State(CST816D->Arduino_IIC_Touch::Device::TOUCH_DEVICE_INTERRUPT_MODE,
                                        CST816D->Arduino_IIC_Touch::Device_Mode::TOUCH_DEVICE_INTERRUPT_PERIODIC);
    }

#else
#error "Unknown macro definition. Please select the correct macro definition."
#endif
}

/* Display flushing */
void my_disp_flush(lv_disp_drv_t *disp, const lv_area_t *area, lv_color_t *color_p)
{
    uint32_t w = (area->x2 - area->x1 + 1);
    uint32_t h = (area->y2 - area->y1 + 1);

#if (LV_COLOR_16_SWAP != 0)
    gfx->draw16bitBeRGBBitmap(area->x1, area->y1, (uint16_t *)&color_p->full, w, h);
#else
    gfx->draw16bitRGBBitmap(area->x1, area->y1, (uint16_t *)&color_p->full, w, h);
#endif

    lv_disp_flush_ready(disp);
}

/*Read the touchpad*/
void my_touchpad_read(lv_indev_drv_t *indev_drv, lv_indev_data_t *data)
{

#if defined DXQ120MYB2416A
    int16_t Touch_x[2], Touch_y[2];
    uint8_t touchpad = touch.getPoint(Touch_x, Touch_y);

    if (touchpad > 0)
    {
        data->state = LV_INDEV_STATE_PR;

        /*Set the coordinates*/
        data->point.x = Touch_x[0];
        data->point.y = Touch_y[0];

        // Serial.print("Data x ");
        // Serial.printf("%d\n", x[0]);

        // Serial.print("Data y ");
        // Serial.printf("%d\n", y[0]);
    }
    else
    {
        data->state = LV_INDEV_STATE_REL;
    }
#elif defined TFD12MASBCTB4_V0_07

    if (CST816D->IIC_Read_Device_Value(CST816D->Arduino_IIC_Touch::Value_Information::TOUCH_FINGER_NUMBER) > 0)
    {

        data->state = LV_INDEV_STATE_PR;

        /*Set the coordinates*/
        data->point.x = (uint32_t)CST816D->IIC_Read_Device_Value(CST816D->Arduino_IIC_Touch::Value_Information::TOUCH_COORDINATE_X);
        data->point.y = (uint32_t)CST816D->IIC_Read_Device_Value(CST816D->Arduino_IIC_Touch::Value_Information::TOUCH_COORDINATE_Y);

        // Serial.print("Data x ");
        // Serial.printf("%d\n", x[0]);

        // Serial.print("Data y ");
        // Serial.printf("%d\n", y[0]);
    }
    else
    {
        data->state = LV_INDEV_STATE_REL;
    }
#else
#error "Unknown macro definition. Please select the correct macro definition."
#endif
}

void my_rounder_cb(lv_disp_drv_t *disp_drv, lv_area_t *area)
{
    if (area->x1 % 2 != 0)
        area->x1 += 1;
    if (area->y1 % 2 != 0)
        area->y1 += 1;

    uint32_t w = (area->x2 - area->x1 + 1);
    uint32_t h = (area->y2 - area->y1 + 1);
    if (w % 2 != 0)
        area->x2 -= 1;
    if (h % 2 != 0)
        area->y2 -= 1;
}

void lvgl_initialization(void)
{
    lv_init();

    CIT_UI.LCD_Width = gfx->width();
    CIT_UI.LCD_Height = gfx->height();

    lv_color_t *buf_1 = (lv_color_t *)heap_caps_malloc(CIT_UI.LCD_Width * CIT_UI.LCD_Height * sizeof(lv_color_t), MALLOC_CAP_SPIRAM | MALLOC_CAP_8BIT);

    while (!buf_1)
    {
        Serial.println("LVGL buf_1 allocate failed!");
        delay(1000);
    }

    lv_disp_draw_buf_init(&draw_buf, buf_1, NULL, CIT_UI.LCD_Width * CIT_UI.LCD_Height * sizeof(lv_color_t));

    /* Initialize the display */
    lv_disp_drv_init(&disp_drv);
    /* Change the following line to your display resolution */
    disp_drv.hor_res = CIT_UI.LCD_Width;
    disp_drv.ver_res = CIT_UI.LCD_Height;
    disp_drv.flush_cb = my_disp_flush;
    disp_drv.rounder_cb = my_rounder_cb;
    disp_drv.draw_buf = &draw_buf;
    lv_disp_drv_register(&disp_drv);

    /*Initialize the (dummy) input device driver*/
    static lv_indev_drv_t indev_drv;
    lv_indev_drv_init(&indev_drv);
    indev_drv.type = LV_INDEV_TYPE_POINTER;
    indev_drv.read_cb = my_touchpad_read;
    lv_indev_drv_register(&indev_drv);
}
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

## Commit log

2025-01-02 Update Tool
    [PCB.dxf, Shell.dxf]
2026-02-26 update structure
    [0-001_10.stl, 0-00_10_5_12.stl, 0-00_15.stl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]
2026-03-26 update Arduino_DriveBus
